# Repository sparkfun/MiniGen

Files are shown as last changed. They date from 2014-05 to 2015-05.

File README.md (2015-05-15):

SparkFun MiniGen - Pro Mini Signal Generator Shield
===================================================

[MiniGen  
*MiniGen Signal Generator (BOB-11420)*](https://www.sparkfun.com/products/11420)

The [MiniGen](https://www.sparkfun.com/products/11420) designed to be used
either as a stand-alone board or as a shield that can be placed on top of an
Arduino Pro Mini. It's capable of generating sine, square or triangle waves at
up to 3MHz, and approximately 1Vp-p. The output is at a DC offset of Vcc/2.
Neither the offset nor the amplitude can be varied.

The MiniGen can be powered by any voltage from 2.3V to 5.5V, so it can be used
with either a 3.3V or 5V Pro Mini without any voltage regulation or signal level
shifting needed.

Repository Contents
-------------------
* **/Hardware** - Eagle design files (.brd, .sch)
* **/Libraries** - Libraries for use with the <PRODUCT NAME>
* **/Production** - Production panel files (.brd)

Documentation
--------------
* **[Library](https://github.com/sparkfun/SparkFun_MiniGen_Arduino_Library)** -  Arduinolibrary for the MiniGen.
* **[Hookup Guide](https://learn.sparkfun.com/tutorials/minigen-hookup-guide)** - Basic hookup guide for the MiniGen.
* **[SparkFun Fritzing repo](https://github.com/sparkfun/Fritzing_Parts)** - Fritzing diagrams for SparkFun products.
* **[SparkFun 3D Model repo](https://github.com/sparkfun/3D_Models)** - 3D models of SparkFun products. 

License Information
-------------------
This product is _**open source**_! 

The **hardware** is released under [Creative Commons ShareAlike 4.0 International](https://creativecommons.org/licenses/by-sa/4.0/).

The **code** is beerware; if you see me (or any other SparkFun employee) at the local, and you've found our code helpful, please buy us a round!

Please use, reuse, and modify these files as you see fit. Please maintain attribution to SparkFun Electronics and release anything derivative under the same license.

Distributed as-is; no warranty is given.

- Your friends at SparkFun.

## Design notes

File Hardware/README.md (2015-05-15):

SparkFun <PRODUCT NAME> Design Files
=====================================

The .sch and .brd files hare are Eagle CAD schematic and PCB design files from SparkFun Electronics.
A freeware version of Eagle can be found [here](http://www.cadsoftusa.com/download-eagle/freeware/). 

License
---------
This product is open source! 
The hardware is released under [Creative Commons ShareAlike 4.0 International](https://creativecommons.org/licenses/by-sa/4.0/).

Please use, reuse, and modify these files as you see fit. Please maintain attribution to SparkFun Electronics and release anything derivative under the same license.

Distributed as-is; no warranty is given.

- Your friends at SparkFun.

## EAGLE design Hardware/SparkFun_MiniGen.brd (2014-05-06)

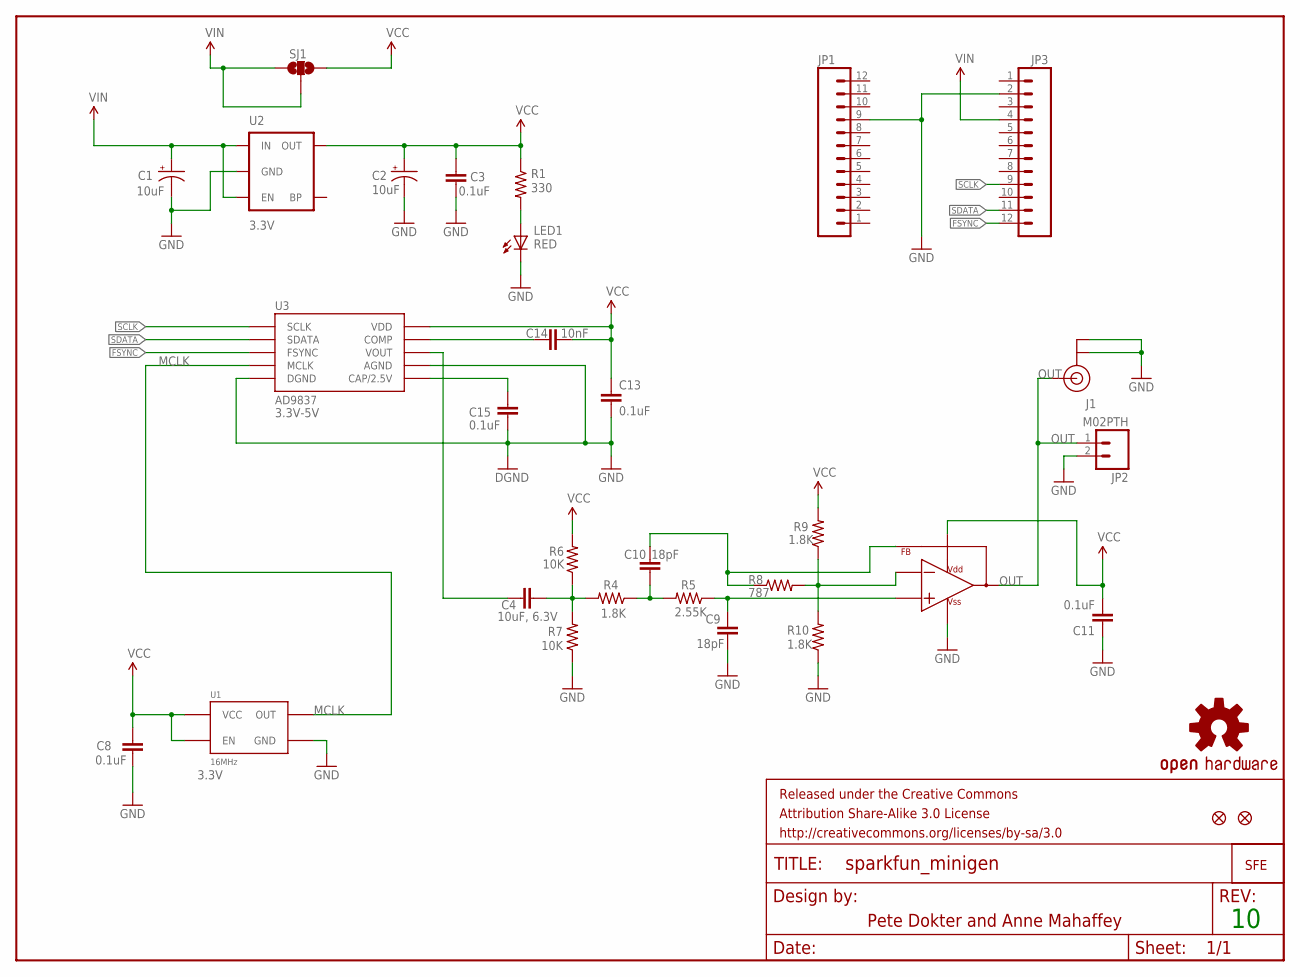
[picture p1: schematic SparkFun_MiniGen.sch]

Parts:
C1, C2: 10uF; EIA3528
C3, C8, C11, C13, C15: 0.1uF; 0603-CAP
C4: 10uF, 6.3V; 0603-CAP
C9, C10: 18pF; 0603-CAP
C14: 10nF; 0603-CAP
FID1, FID2: FIDUCIAL1X2; FIDUCIAL-1X2
FRAME1: FRAME-LETTER; CREATIVE_COMMONS
J1: U.FL
JP1, JP3: M12PTH; 1X12
JP2: M02PTH; 1X02
JP4: LOGO-SFENEW; SFE-NEW-WEBLOGO
LED1: RED; LED-0603
R1: 330; 0603-RES
R4, R9, R10: 1.8K; 0603-RES
R5: 2.55K; 0603-RES
R6, R7: 10K; 0603-RES
R8: 787; 0603-RES
SJ1: SOLDERJUMPER_2WAYT; SJ_2
U1: 16MHz; CRYSTAL-SMD-7X5
U2: 3.3V; SOT23-5
U3: AD9837
U4: ADC8045; SO08
U$2: OSHW-LOGOS; OSHW-LOGO-S

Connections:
FSYNC: JP3.12, U3.P$8 (FSYNC)
GND: C1.C (-), C2.C (-), C3.2, C8.2, C9.1, C11.1, C13.2, C15.2, J1.P$1 (GND), J1.P$2 (GND), JP1.9, JP2.2, JP3.2, LED1.C, R7.1, R10.1, U1.P$2 (GND), U2.2 (GND), U3.P$0 (DGND), U3.P$4 (DGND), U3.P$9 (AGND), U4.4 (VSS)
MCLK: U1.P$3 (OUT), U3.P$5 (MCLK)
unnamed: LED1.A, R1.2
unnamed: C9.2, R5.1, U4.3 (IN+)
unnamed: C10.1, R4.1, R5.2
unnamed: C10.2, R8.1, U4.1 (FB)
unnamed: C15.1, U3.P$3 (CAP/2.5V)
unnamed: R8.2, R9.1, R10.2, U4.2 (IN-)
unnamed: C4.2, R4.2, R6.1, R7.2
unnamed: C4.1, U3.P$10 (VOUT)
unnamed: C14.1, U3.P$1 (COMP)
OUT: J1.P$3 (SIGNAL), JP2.1, U4.6 (OUT)
SCLK: JP3.9, U3.P$7 (SCLK)
SDATA: JP3.11, U3.P$6 (SDATA)
VCC: C2.A (+), C3.1, C8.1, C11.2, C13.1, C14.2, R1.1, R6.2, R9.2, SJ1.3, U1.P$1 (EN), U1.P$4 (VCC), U2.5 (OUT), U3.P$2 (VDD), U4.7 (VDD)
VIN: C1.A (+), JP3.4, SJ1.1, SJ1.2, U2.1 (IN), U2.3 (EN)

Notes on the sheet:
Pete Dokter and Anne Mahaffey
3.3V
3.3V-5V

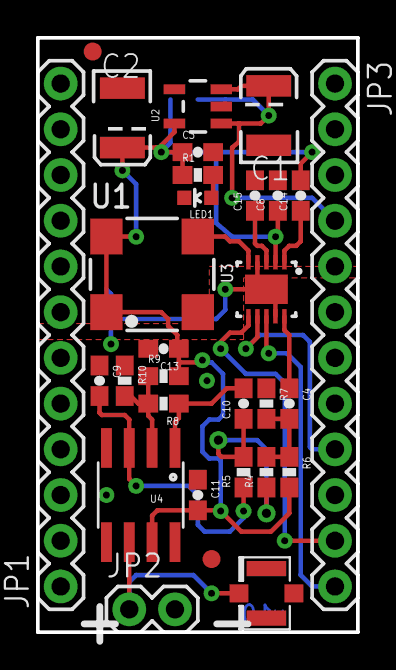
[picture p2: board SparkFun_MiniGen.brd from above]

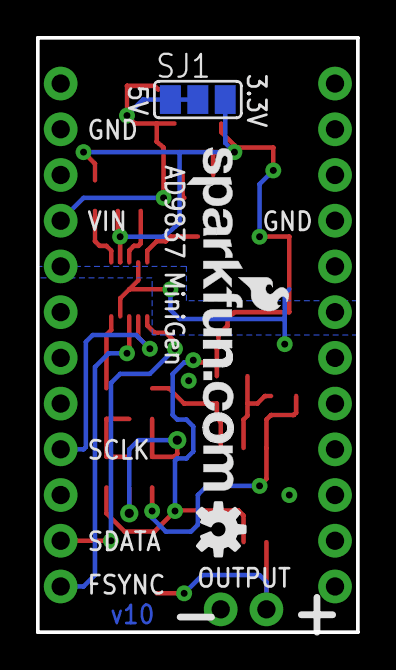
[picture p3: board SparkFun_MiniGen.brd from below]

Board: 2 copper layers, 17.8 x 33.0 mm, 34 parts (3 on the bottom side), 17 nets.

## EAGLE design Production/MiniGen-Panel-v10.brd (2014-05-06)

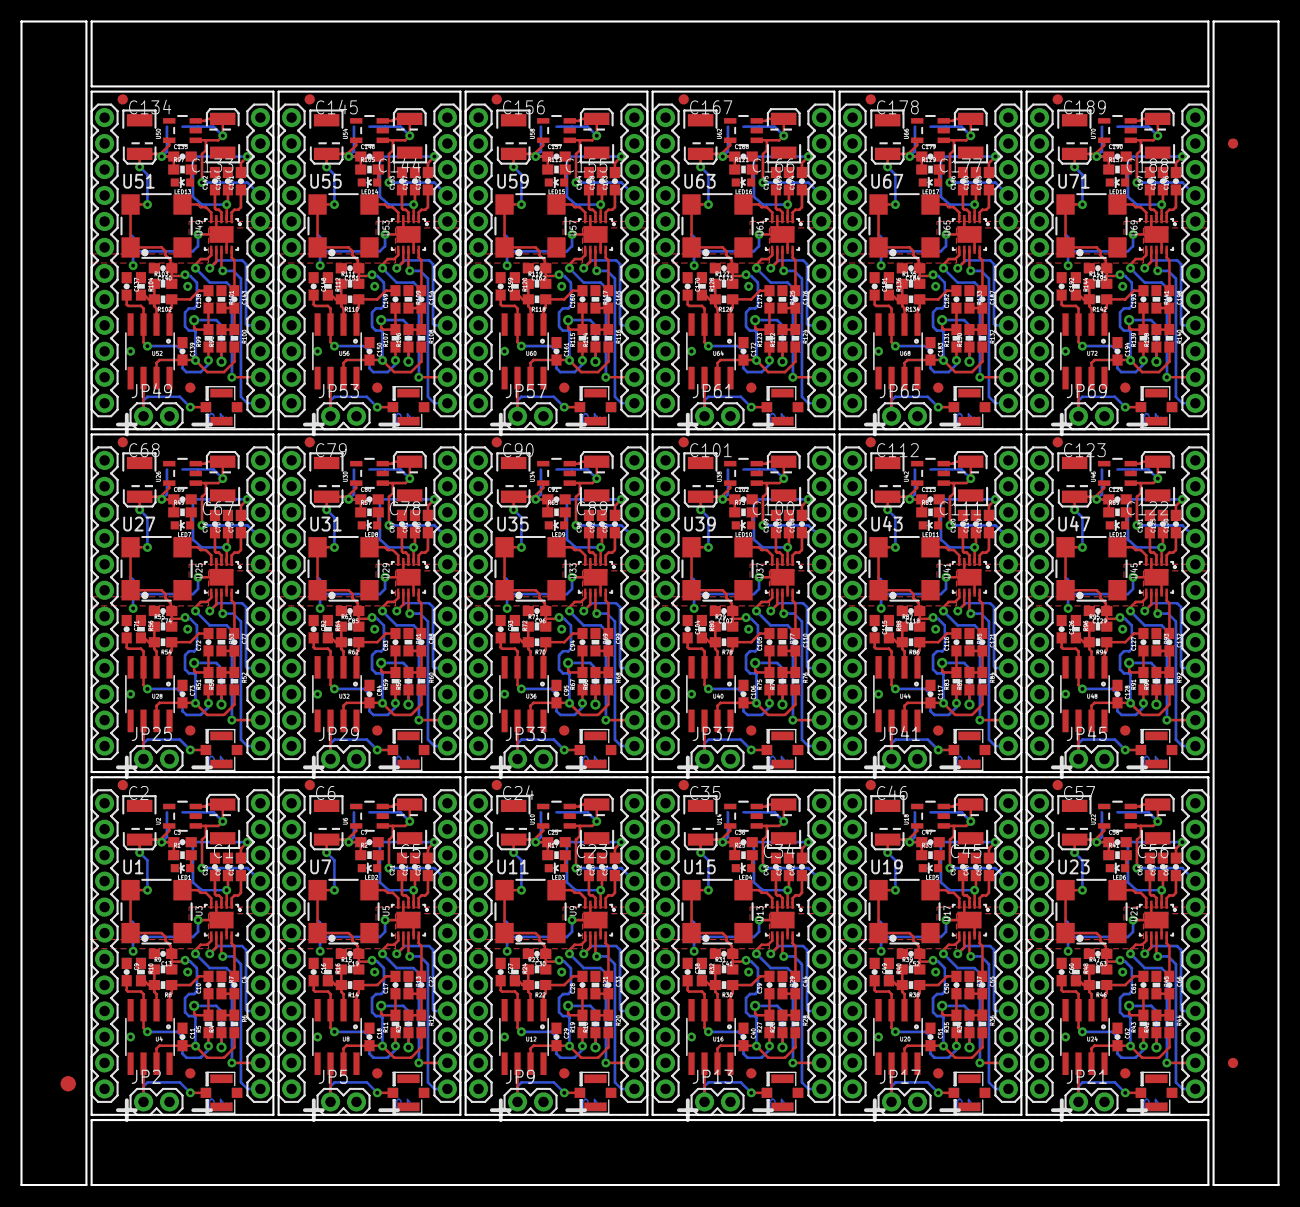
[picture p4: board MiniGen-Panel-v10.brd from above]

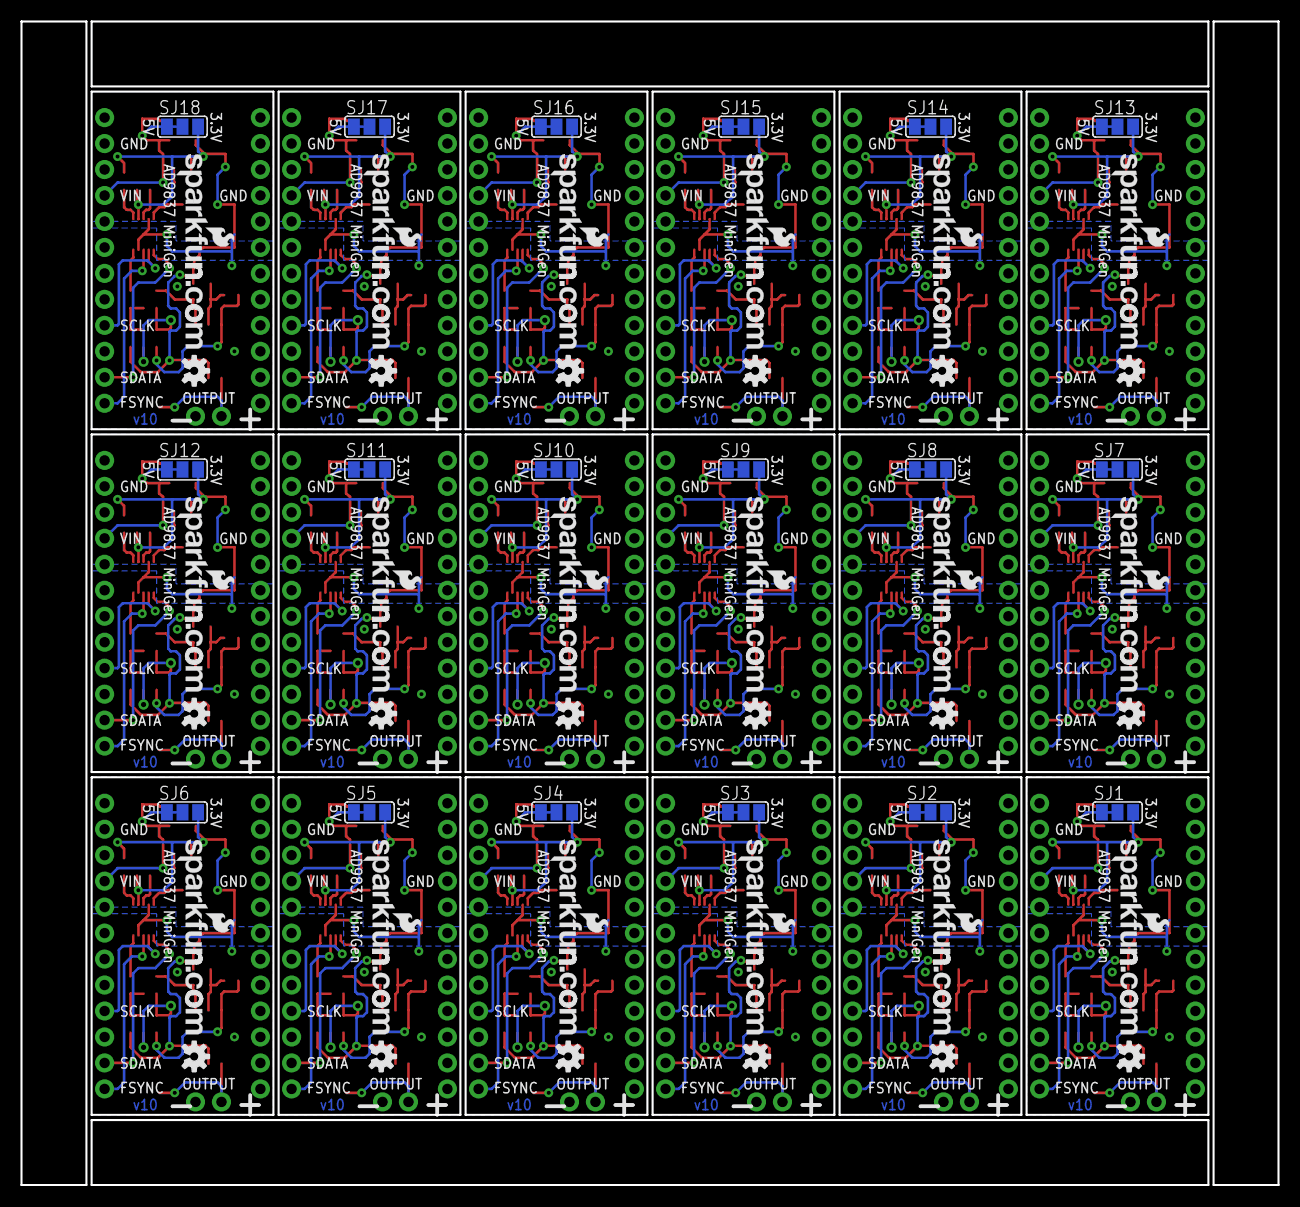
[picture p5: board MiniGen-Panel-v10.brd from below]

Board: 2 copper layers, 122.9 x 113.8 mm, 597 parts (54 on the bottom side), 306 nets.

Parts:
C1, C2, C5, C6, C23, C24, C34, C35, C45, C46, C56, C57, C67, C68, C78, C79, C89, C90, C100, C101, C111, C112, C122, C123, C133, C134, C144, C145, C155, C156, C166, C167, C177, C178, C188, C189: 10uF; EIA3528
C3, C7, C8, C11, C12, C13, C15, C18, C19, C21, C25, C26, C29, C30, C32, C36, C37, C40, C41, C43, C47, C48, C51, C52, C54, C58, C59, C62, C63, C65, C69, C70, C73, C74, C76, C80, C81, C84, C85, C87, C91, C92, C95, C96, C98, C102, C103, C106, C107, C109, C113, C114, C117, C118, C120, C124, C125, C128, C129, C131, C135, C136, C139, C140, C142, C146, C147, C150, C151, C153, C157, C158, C161, C162, C164, C168, C169, C172, C173, C175, C179, C180, C183, C184, C186, C190, C191, C194, C195, C197: 0.1uF; 0603-CAP
C4, C22, C33, C44, C55, C66, C77, C88, C99, C110, C121, C132, C143, C154, C165, C176, C187, C198: 10uF, 6.3V; 0603-CAP
C9, C10, C16, C17, C27, C28, C38, C39, C49, C50, C60, C61, C71, C72, C82, C83, C93, C94, C104, C105, C115, C116, C126, C127, C137, C138, C148, C149, C159, C160, C170, C171, C181, C182, C192, C193: 18pF; 0603-CAP
C14, C20, C31, C42, C53, C64, C75, C86, C97, C108, C119, C130, C141, C152, C163, C174, C185, C196: 10nF; 0603-CAP
E$1: FIDUCIAL-1.5X3
E$4, E$6: FIDUCIAL-1X2
FID1, FID2, FID3, FID4, FID5, FID6, FID7, FID8, FID9, FID10, FID11, FID12, FID13, FID14, FID15, FID16, FID17, FID18, FID19, FID20, FID21, FID22, FID23, FID24, FID25, FID26, FID27, FID28, FID29, FID30, FID31, FID32, FID33, FID34, FID35, FID36: FIDUCIAL1X2; FIDUCIAL-1X2
J1, J2, J3, J4, J5, J6, J7, J8, J9, J10, J11, J12, J13, J14, J15, J16, J17, J18: U.FL
JP1, JP3, JP6, JP7, JP10, JP11, JP14, JP15, JP18, JP19, JP22, JP23, JP26, JP27, JP30, JP31, JP34, JP35, JP38, JP39, JP42, JP43, JP46, JP47, JP50, JP51, JP54, JP55, JP58, JP59, JP62, JP63, JP66, JP67, JP70, JP71: M12PTH; 1X12
JP2, JP5, JP9, JP13, JP17, JP21, JP25, JP29, JP33, JP37, JP41, JP45, JP49, JP53, JP57, JP61, JP65, JP69: M02PTH; 1X02
JP4, JP8, JP12, JP16, JP20, JP24, JP28, JP32, JP36, JP40, JP44, JP48, JP52, JP56, JP60, JP64, JP68, JP72: LOGO-SFENEW; SFE-NEW-WEBLOGO
LED1, LED2, LED3, LED4, LED5, LED6, LED7, LED8, LED9, LED10, LED11, LED12, LED13, LED14, LED15, LED16, LED17, LED18: RED; LED-0603
R1, R2, R17, R25, R33, R41, R49, R57, R65, R73, R81, R89, R97, R105, R113, R121, R129, R137: 330; 0603-RES
R3, R4, R9, R10, R15, R16, R18, R23, R24, R26, R31, R32, R34, R39, R40, R42, R47, R48, R50, R55, R56, R58, R63, R64, R66, R71, R72, R74, R79, R80, R82, R87, R88, R90, R95, R96, R98, R103, R104, R106, R111, R112, R114, R119, R120, R122, R127, R128, R130, R135, R136, R138, R143, R144: 1.8K; 0603-RES
R5, R11, R19, R27, R35, R43, R51, R59, R67, R75, R83, R91, R99, R107, R115, R123, R131, R139: 2.55K; 0603-RES
R6, R7, R12, R13, R20, R21, R28, R29, R36, R37, R44, R45, R52, R53, R60, R61, R68, R69, R76, R77, R84, R85, R92, R93, R100, R101, R108, R109, R116, R117, R124, R125, R132, R133, R140, R141: 10K; 0603-RES
R8, R14, R22, R30, R38, R46, R54, R62, R70, R78, R86, R94, R102, R110, R118, R126, R134, R142: 787; 0603-RES
SJ1, SJ2, SJ3, SJ4, SJ5, SJ6, SJ7, SJ8, SJ9, SJ10, SJ11, SJ12, SJ13, SJ14, SJ15, SJ16, SJ17, SJ18: SJ_2
U1, U7, U11, U15, U19, U23, U27, U31, U35, U39, U43, U47, U51, U55, U59, U63, U67, U71: 16MHz; CRYSTAL-SMD-7X5
U2, U6, U10, U14, U18, U22, U26, U30, U34, U38, U42, U46, U50, U54, U58, U62, U66, U70: 3.3V; SOT23-5
U3, U5, U9, U13, U17, U21, U25, U29, U33, U37, U41, U45, U49, U53, U57, U61, U65, U69: AD9837
U4, U8, U12, U16, U20, U24, U28, U32, U36, U40, U44, U48, U52, U56, U60, U64, U68, U72: SO08
U$1, U$2, U$3, U$4, U$5, U$6, U$7, U$8, U$9, U$10, U$11, U$12, U$13, U$14, U$15, U$16, U$17, U$18: OSHW-LOGOS; OSHW-LOGO-S

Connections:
FSYNC: JP3.12, U3.P$8
FSYNC1: JP7.12, U5.P$8
FSYNC2: JP11.12, U9.P$8
FSYNC3: JP15.12, U13.P$8
FSYNC4: JP19.12, U17.P$8
FSYNC5: JP23.12, U21.P$8
FSYNC6: JP27.12, U25.P$8
FSYNC7: JP31.12, U29.P$8
FSYNC8: JP35.12, U33.P$8
FSYNC9: JP39.12, U37.P$8
FSYNC10: JP43.12, U41.P$8
FSYNC11: JP47.12, U45.P$8
FSYNC12: JP51.12, U49.P$8
FSYNC13: JP55.12, U53.P$8
FSYNC14: JP59.12, U57.P$8
FSYNC15: JP63.12, U61.P$8
FSYNC16: JP67.12, U65.P$8
FSYNC17: JP71.12, U69.P$8
GND: C1.C, C2.C, C3.2, C8.2, C9.1, C11.1, C13.2, C15.2, J1.P$1, J1.P$2, JP1.9, JP2.2, JP3.2, LED1.C, R7.1, R10.1, U1.P$2, U2.2, U3.P$0, U3.P$4, U3.P$9, U4.4
GND1: C5.C, C6.C, C7.2, C12.2, C16.1, C18.1, C19.2, C21.2, J2.P$1, J2.P$2, JP5.2, JP6.9, JP7.2, LED2.C, R13.1, R16.1, U5.P$0, U5.P$4, U5.P$9, U6.2, U7.P$2, U8.4
GND2: C23.C, C24.C, C25.2, C26.2, C27.1, C29.1, C30.2, C32.2, J3.P$1, J3.P$2, JP9.2, JP10.9, JP11.2, LED3.C, R21.1, R24.1, U9.P$0, U9.P$4, U9.P$9, U10.2, U11.P$2, U12.4
GND3: C34.C, C35.C, C36.2, C37.2, C38.1, C40.1, C41.2, C43.2, J4.P$1, J4.P$2, JP13.2, JP14.9, JP15.2, LED4.C, R29.1, R32.1, U13.P$0, U13.P$4, U13.P$9, U14.2, U15.P$2, U16.4
GND4: C45.C, C46.C, C47.2, C48.2, C49.1, C51.1, C52.2, C54.2, J5.P$1, J5.P$2, JP17.2, JP18.9, JP19.2, LED5.C, R37.1, R40.1, U17.P$0, U17.P$4, U17.P$9, U18.2, U19.P$2, U20.4
GND5: C56.C, C57.C, C58.2, C59.2, C60.1, C62.1, C63.2, C65.2, J6.P$1, J6.P$2, JP21.2, JP22.9, JP23.2, LED6.C, R45.1, R48.1, U21.P$0, U21.P$4, U21.P$9, U22.2, U23.P$2, U24.4
GND6: C67.C, C68.C, C69.2, C70.2, C71.1, C73.1, C74.2, C76.2, J7.P$1, J7.P$2, JP25.2, JP26.9, JP27.2, LED7.C, R53.1, R56.1, U25.P$0, U25.P$4, U25.P$9, U26.2, U27.P$2, U28.4
GND7: C78.C, C79.C, C80.2, C81.2, C82.1, C84.1, C85.2, C87.2, J8.P$1, J8.P$2, JP29.2, JP30.9, JP31.2, LED8.C, R61.1, R64.1, U29.P$0, U29.P$4, U29.P$9, U30.2, U31.P$2, U32.4
GND8: C89.C, C90.C, C91.2, C92.2, C93.1, C95.1, C96.2, C98.2, J9.P$1, J9.P$2, JP33.2, JP34.9, JP35.2, LED9.C, R69.1, R72.1, U33.P$0, U33.P$4, U33.P$9, U34.2, U35.P$2, U36.4
GND9: C100.C, C101.C, C102.2, C103.2, C104.1, C106.1, C107.2, C109.2, J10.P$1, J10.P$2, JP37.2, JP38.9, JP39.2, LED10.C, R77.1, R80.1, U37.P$0, U37.P$4, U37.P$9, U38.2, U39.P$2, U40.4
GND10: C111.C, C112.C, C113.2, C114.2, C115.1, C117.1, C118.2, C120.2, J11.P$1, J11.P$2, JP41.2, JP42.9, JP43.2, LED11.C, R85.1, R88.1, U41.P$0, U41.P$4, U41.P$9, U42.2, U43.P$2, U44.4
GND11: C122.C, C123.C, C124.2, C125.2, C126.1, C128.1, C129.2, C131.2, J12.P$1, J12.P$2, JP45.2, JP46.9, JP47.2, LED12.C, R93.1, R96.1, U45.P$0, U45.P$4, U45.P$9, U46.2, U47.P$2, U48.4
GND12: C133.C, C134.C, C135.2, C136.2, C137.1, C139.1, C140.2, C142.2, J13.P$1, J13.P$2, JP49.2, JP50.9, JP51.2, LED13.C, R101.1, R104.1, U49.P$0, U49.P$4, U49.P$9, U50.2, U51.P$2, U52.4
GND13: C144.C, C145.C, C146.2, C147.2, C148.1, C150.1, C151.2, C153.2, J14.P$1, J14.P$2, JP53.2, JP54.9, JP55.2, LED14.C, R109.1, R112.1, U53.P$0, U53.P$4, U53.P$9, U54.2, U55.P$2, U56.4
GND14: C155.C, C156.C, C157.2, C158.2, C159.1, C161.1, C162.2, C164.2, J15.P$1, J15.P$2, JP57.2, JP58.9, JP59.2, LED15.C, R117.1, R120.1, U57.P$0, U57.P$4, U57.P$9, U58.2, U59.P$2, U60.4
GND15: C166.C, C167.C, C168.2, C169.2, C170.1, C172.1, C173.2, C175.2, J16.P$1, J16.P$2, JP61.2, JP62.9, JP63.2, LED16.C, R125.1, R128.1, U61.P$0, U61.P$4, U61.P$9, U62.2, U63.P$2, U64.4
GND16: C177.C, C178.C, C179.2, C180.2, C181.1, C183.1, C184.2, C186.2, J17.P$1, J17.P$2, JP65.2, JP66.9, JP67.2, LED17.C, R133.1, R136.1, U65.P$0, U65.P$4, U65.P$9, U66.2, U67.P$2, U68.4
GND17: C188.C, C189.C, C190.2, C191.2, C192.1, C194.1, C195.2, C197.2, J18.P$1, J18.P$2, JP69.2, JP70.9, JP71.2, LED18.C, R141.1, R144.1, U69.P$0, U69.P$4, U69.P$9, U70.2, U71.P$2, U72.4
MCLK: U1.P$3, U3.P$5
MCLK1: U5.P$5, U7.P$3
MCLK2: U9.P$5, U11.P$3
MCLK3: U13.P$5, U15.P$3
MCLK4: U17.P$5, U19.P$3
MCLK5: U21.P$5, U23.P$3
MCLK6: U25.P$5, U27.P$3
MCLK7: U29.P$5, U31.P$3
MCLK8: U33.P$5, U35.P$3
MCLK9: U37.P$5, U39.P$3
MCLK10: U41.P$5, U43.P$3
MCLK11: U45.P$5, U47.P$3
MCLK12: U49.P$5, U51.P$3
MCLK13: U53.P$5, U55.P$3
MCLK14: U57.P$5, U59.P$3
MCLK15: U61.P$5, U63.P$3
MCLK16: U65.P$5, U67.P$3
MCLK17: U69.P$5, U71.P$3
unnamed: LED2.A, R2.2
unnamed: C22.2, R3.2, R12.1, R13.2
unnamed: LED1.A, R1.2
unnamed: C22.1, U5.P$10
unnamed: C20.1, U5.P$1
unnamed: C21.1, U5.P$3
unnamed: C9.2, R5.1, U4.3
unnamed: C10.1, R4.1, R5.2
unnamed: C10.2, R8.1, U4.1
unnamed: C15.1, U3.P$3
unnamed: C16.2, R11.1, U8.3
unnamed: R8.2, R9.1, R10.2, U4.2
unnamed: C17.1, R3.1, R11.2
unnamed: C4.2, R4.2, R6.1, R7.2
unnamed: R14.2, R15.1, R16.2, U8.2
unnamed: C17.2, R14.1, U8.1
unnamed: LED3.A, R17.2
unnamed: C33.2, R18.2, R20.1, R21.2
unnamed: C33.1, U9.P$10
unnamed: C31.1, U9.P$1
unnamed: C4.1, U3.P$10
unnamed: C32.1, U9.P$3
unnamed: C14.1, U3.P$1
unnamed: C27.2, R19.1, U12.3
unnamed: C28.1, R18.1, R19.2
unnamed: R22.2, R23.1, R24.2, U12.2
unnamed: C28.2, R22.1, U12.1
unnamed: LED4.A, R25.2
unnamed: C44.2, R26.2, R28.1, R29.2
unnamed: C44.1, U13.P$10
unnamed: C42.1, U13.P$1
unnamed: C43.1, U13.P$3
unnamed: C38.2, R27.1, U16.3
unnamed: C39.1, R26.1, R27.2
unnamed: R30.2, R31.1, R32.2, U16.2
unnamed: C39.2, R30.1, U16.1
unnamed: LED5.A, R33.2
unnamed: C55.2, R34.2, R36.1, R37.2
unnamed: C55.1, U17.P$10
unnamed: C53.1, U17.P$1
unnamed: C54.1, U17.P$3
unnamed: C49.2, R35.1, U20.3
unnamed: C50.1, R34.1, R35.2
unnamed: R38.2, R39.1, R40.2, U20.2
unnamed: C50.2, R38.1, U20.1
unnamed: LED6.A, R41.2
unnamed: C66.2, R42.2, R44.1, R45.2
unnamed: C66.1, U21.P$10
unnamed: C64.1, U21.P$1
unnamed: C65.1, U21.P$3
unnamed: C60.2, R43.1, U24.3
unnamed: C61.1, R42.1, R43.2
unnamed: R46.2, R47.1, R48.2, U24.2
unnamed: C61.2, R46.1, U24.1
unnamed: LED7.A, R49.2
unnamed: C77.2, R50.2, R52.1, R53.2
unnamed: C77.1, U25.P$10
unnamed: C75.1, U25.P$1
unnamed: C76.1, U25.P$3
unnamed: C71.2, R51.1, U28.3
unnamed: C72.1, R50.1, R51.2
unnamed: R54.2, R55.1, R56.2, U28.2
unnamed: C72.2, R54.1, U28.1
unnamed: LED8.A, R57.2
unnamed: C88.2, R58.2, R60.1, R61.2
unnamed: C88.1, U29.P$10
unnamed: C86.1, U29.P$1
unnamed: C87.1, U29.P$3
unnamed: C82.2, R59.1, U32.3
unnamed: C83.1, R58.1, R59.2
unnamed: R62.2, R63.1, R64.2, U32.2
unnamed: C83.2, R62.1, U32.1
unnamed: LED9.A, R65.2
unnamed: C99.2, R66.2, R68.1, R69.2
unnamed: C99.1, U33.P$10
unnamed: C97.1, U33.P$1
unnamed: C98.1, U33.P$3
unnamed: C93.2, R67.1, U36.3
unnamed: C94.1, R66.1, R67.2
unnamed: R70.2, R71.1, R72.2, U36.2
unnamed: C94.2, R70.1, U36.1
unnamed: LED10.A, R73.2
unnamed: C110.2, R74.2, R76.1, R77.2
unnamed: C110.1, U37.P$10
unnamed: C108.1, U37.P$1
unnamed: C109.1, U37.P$3
unnamed: C104.2, R75.1, U40.3
unnamed: C105.1, R74.1, R75.2
unnamed: R78.2, R79.1, R80.2, U40.2
unnamed: C105.2, R78.1, U40.1
unnamed: LED11.A, R81.2
unnamed: C121.2, R82.2, R84.1, R85.2
unnamed: C121.1, U41.P$10
unnamed: C119.1, U41.P$1
unnamed: C120.1, U41.P$3
unnamed: C115.2, R83.1, U44.3
unnamed: C116.1, R82.1, R83.2
unnamed: R86.2, R87.1, R88.2, U44.2
unnamed: C116.2, R86.1, U44.1
unnamed: LED12.A, R89.2
unnamed: C132.2, R90.2, R92.1, R93.2
unnamed: C132.1, U45.P$10
unnamed: C130.1, U45.P$1
unnamed: C131.1, U45.P$3
unnamed: C126.2, R91.1, U48.3
unnamed: C127.1, R90.1, R91.2
unnamed: R94.2, R95.1, R96.2, U48.2
unnamed: C127.2, R94.1, U48.1
unnamed: LED13.A, R97.2
unnamed: C143.2, R98.2, R100.1, R101.2
unnamed: C143.1, U49.P$10
unnamed: C141.1, U49.P$1
unnamed: C142.1, U49.P$3
unnamed: C137.2, R99.1, U52.3
unnamed: C138.1, R98.1, R99.2
unnamed: R102.2, R103.1, R104.2, U52.2
unnamed: C138.2, R102.1, U52.1
unnamed: LED14.A, R105.2
unnamed: C154.2, R106.2, R108.1, R109.2
unnamed: C154.1, U53.P$10
unnamed: C152.1, U53.P$1
unnamed: C153.1, U53.P$3
unnamed: C148.2, R107.1, U56.3
unnamed: C149.1, R106.1, R107.2
unnamed: R110.2, R111.1, R112.2, U56.2
unnamed: C149.2, R110.1, U56.1
unnamed: LED15.A, R113.2
unnamed: C165.2, R114.2, R116.1, R117.2
unnamed: C165.1, U57.P$10
unnamed: C163.1, U57.P$1
unnamed: C164.1, U57.P$3
unnamed: C159.2, R115.1, U60.3
unnamed: C160.1, R114.1, R115.2
unnamed: R118.2, R119.1, R120.2, U60.2
unnamed: C160.2, R118.1, U60.1
unnamed: LED16.A, R121.2
unnamed: C176.2, R122.2, R124.1, R125.2
unnamed: C176.1, U61.P$10
unnamed: C174.1, U61.P$1
unnamed: C175.1, U61.P$3
unnamed: C170.2, R123.1, U64.3
unnamed: C171.1, R122.1, R123.2
unnamed: R126.2, R127.1, R128.2, U64.2
unnamed: C171.2, R126.1, U64.1
unnamed: LED17.A, R129.2
unnamed: C187.2, R130.2, R132.1, R133.2
unnamed: C187.1, U65.P$10
unnamed: C185.1, U65.P$1
unnamed: C186.1, U65.P$3
unnamed: C181.2, R131.1, U68.3
unnamed: C182.1, R130.1, R131.2
unnamed: R134.2, R135.1, R136.2, U68.2
unnamed: C182.2, R134.1, U68.1
unnamed: LED18.A, R137.2
unnamed: C198.2, R138.2, R140.1, R141.2
unnamed: C198.1, U69.P$10
unnamed: C196.1, U69.P$1
unnamed: C197.1, U69.P$3
unnamed: C192.2, R139.1, U72.3
unnamed: C193.1, R138.1, R139.2
unnamed: R142.2, R143.1, R144.2, U72.2
unnamed: C193.2, R142.1, U72.1
OUT: J1.P$3, JP2.1, U4.6
OUT1: J2.P$3, JP5.1, U8.6
OUT2: J3.P$3, JP9.1, U12.6
OUT3: J4.P$3, JP13.1, U16.6
OUT4: J5.P$3, JP17.1, U20.6
OUT5: J6.P$3, JP21.1, U24.6
OUT6: J7.P$3, JP25.1, U28.6
OUT7: J8.P$3, JP29.1, U32.6
OUT8: J9.P$3, JP33.1, U36.6
OUT9: J10.P$3, JP37.1, U40.6
OUT10: J11.P$3, JP41.1, U44.6
OUT11: J12.P$3, JP45.1, U48.6
OUT12: J13.P$3, JP49.1, U52.6
OUT13: J14.P$3, JP53.1, U56.6
OUT14: J15.P$3, JP57.1, U60.6
OUT15: J16.P$3, JP61.1, U64.6
OUT16: J17.P$3, JP65.1, U68.6
OUT17: J18.P$3, JP69.1, U72.6
SCLK: JP3.9, U3.P$7
SCLK1: JP7.9, U5.P$7
SCLK2: JP11.9, U9.P$7
SCLK3: JP15.9, U13.P$7
SCLK4: JP19.9, U17.P$7
SCLK5: JP23.9, U21.P$7
SCLK6: JP27.9, U25.P$7
SCLK7: JP31.9, U29.P$7
SCLK8: JP35.9, U33.P$7
SCLK9: JP39.9, U37.P$7
SCLK10: JP43.9, U41.P$7
SCLK11: JP47.9, U45.P$7
SCLK12: JP51.9, U49.P$7
SCLK13: JP55.9, U53.P$7
SCLK14: JP59.9, U57.P$7
SCLK15: JP63.9, U61.P$7
SCLK16: JP67.9, U65.P$7
SCLK17: JP71.9, U69.P$7
SDATA: JP3.11, U3.P$6
SDATA1: JP7.11, U5.P$6
SDATA2: JP11.11, U9.P$6
SDATA3: JP15.11, U13.P$6
SDATA4: JP19.11, U17.P$6
SDATA5: JP23.11, U21.P$6
SDATA6: JP27.11, U25.P$6
SDATA7: JP31.11, U29.P$6
SDATA8: JP35.11, U33.P$6
SDATA9: JP39.11, U37.P$6
SDATA10: JP43.11, U41.P$6
SDATA11: JP47.11, U45.P$6
SDATA12: JP51.11, U49.P$6
SDATA13: JP55.11, U53.P$6
SDATA14: JP59.11, U57.P$6
SDATA15: JP63.11, U61.P$6
SDATA16: JP67.11, U65.P$6
SDATA17: JP71.11, U69.P$6
VCC: C2.A, C3.1, C8.1, C11.2, C13.1, C14.2, R1.1, R6.2, R9.2, SJ1.3, U1.P$1, U1.P$4, U2.5, U3.P$2, U4.7
VCC1: C6.A, C7.1, C12.1, C18.2, C19.1, C20.2, R2.1, R12.2, R15.2, SJ2.3, U5.P$2, U6.5, U7.P$1, U7.P$4, U8.7
VCC2: C24.A, C25.1, C26.1, C29.2, C30.1, C31.2, R17.1, R20.2, R23.2, SJ3.3, U9.P$2, U10.5, U11.P$1, U11.P$4, U12.7
VCC3: C35.A, C36.1, C37.1, C40.2, C41.1, C42.2, R25.1, R28.2, R31.2, SJ4.3, U13.P$2, U14.5, U15.P$1, U15.P$4, U16.7
VCC4: C46.A, C47.1, C48.1, C51.2, C52.1, C53.2, R33.1, R36.2, R39.2, SJ5.3, U17.P$2, U18.5, U19.P$1, U19.P$4, U20.7
VCC5: C57.A, C58.1, C59.1, C62.2, C63.1, C64.2, R41.1, R44.2, R47.2, SJ6.3, U21.P$2, U22.5, U23.P$1, U23.P$4, U24.7
VCC6: C68.A, C69.1, C70.1, C73.2, C74.1, C75.2, R49.1, R52.2, R55.2, SJ7.3, U25.P$2, U26.5, U27.P$1, U27.P$4, U28.7
VCC7: C79.A, C80.1, C81.1, C84.2, C85.1, C86.2, R57.1, R60.2, R63.2, SJ8.3, U29.P$2, U30.5, U31.P$1, U31.P$4, U32.7
VCC8: C90.A, C91.1, C92.1, C95.2, C96.1, C97.2, R65.1, R68.2, R71.2, SJ9.3, U33.P$2, U34.5, U35.P$1, U35.P$4, U36.7
VCC9: C101.A, C102.1, C103.1, C106.2, C107.1, C108.2, R73.1, R76.2, R79.2, SJ10.3, U37.P$2, U38.5, U39.P$1, U39.P$4, U40.7
VCC10: C112.A, C113.1, C114.1, C117.2, C118.1, C119.2, R81.1, R84.2, R87.2, SJ11.3, U41.P$2, U42.5, U43.P$1, U43.P$4, U44.7
VCC11: C123.A, C124.1, C125.1, C128.2, C129.1, C130.2, R89.1, R92.2, R95.2, SJ12.3, U45.P$2, U46.5, U47.P$1, U47.P$4, U48.7
VCC12: C134.A, C135.1, C136.1, C139.2, C140.1, C141.2, R97.1, R100.2, R103.2, SJ13.3, U49.P$2, U50.5, U51.P$1, U51.P$4, U52.7
VCC13: C145.A, C146.1, C147.1, C150.2, C151.1, C152.2, R105.1, R108.2, R111.2, SJ14.3, U53.P$2, U54.5, U55.P$1, U55.P$4, U56.7
VCC14: C156.A, C157.1, C158.1, C161.2, C162.1, C163.2, R113.1, R116.2, R119.2, SJ15.3, U57.P$2, U58.5, U59.P$1, U59.P$4, U60.7
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

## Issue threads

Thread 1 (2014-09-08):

No communication?

dlangis, 2014-09-08:
Has anyone used this board and library successfully?

I have my MiniGen hooked up to an Arduino Uno at the moment (using 3.3 V, with pins connected to SPI pins as appropriate).

When I upload the code, the MiniGen outputs a clean 1.09 Vpp sine wave, running at 62.5 kHz.  However, the Library Test code (or any of my attempts to modify it) don't seem to be updating any of the registers on the MiniGen itself to change the frequency or  wave type.  It seems to be stuck where it is.

I have used SPI communication with the DS3234 "Dead-on RTC" successfully before for writing registers and alarms.  Doesn't seem to be working here though.  Any suggestions on where to start?

ToniCorinne, 2016-07-19:
Apologies on the long delay in answering this. For anyone who also might be having issues with this, please keep in mind this spec point:

> By default, the MiniGen ships configured with a 3.3V regulator enabled and should only be used with 3.3V signals (or 3.3V Pro Minis if you are using this as a shield) unless the jumper on the back is soldered over to bypass the regulator for 5V use.

Double check that you are using signals at the appropriate voltage when interfacing with the board to ensure proper functionality.

Closing this issue out, but if you do still have additional questions, please let us know.

Closed 2016-07-19.

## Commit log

2014-01-21 Initial file commit
    [MiniGen.brd, MiniGen.sch]
2014-01-22 Added version info.
    [MiniGen.brd, MiniGen.sch]
2014-02-07 Update lib to default to pin 10 for CS
2014-02-07 Advance design to v10 for release.
    [MiniGen.brd, MiniGen.sch]
2014-02-10 Fix labeling on schematic
    [MiniGen.brd, MiniGen.sch]
2014-02-11 Add/modify some silk for release.
    [MiniGen.brd]
2014-02-11 added fiducials
    [MiniGen.brd, MiniGen.sch]
2014-02-11 created panel v10
    [MiniGen-Panel-v10.brd]
2014-05-22 Line ending changes
    [MiniGen-Panel-v10.brd, MiniGen.brd, MiniGen.sch]
2015-05-15 Fixing directory structure, naming conventions
    [MiniGen-Panel-v10.brd, MiniGen.brd, MiniGen.sch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]
2015-05-15 Squashed 'Libraries/Arduino/' content from commit 7212493
    git-subtree-dir: Libraries/Arduino
    git-subtree-split: 7212493b946ac81a992486eb619213eb8305324d

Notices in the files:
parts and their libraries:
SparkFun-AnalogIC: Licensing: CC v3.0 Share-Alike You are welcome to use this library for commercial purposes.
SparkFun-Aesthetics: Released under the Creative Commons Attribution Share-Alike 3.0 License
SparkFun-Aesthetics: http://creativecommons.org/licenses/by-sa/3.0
